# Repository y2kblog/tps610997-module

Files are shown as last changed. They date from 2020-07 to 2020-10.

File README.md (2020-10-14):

# TPS610997 超低消費電力 5V出力昇圧モジュール

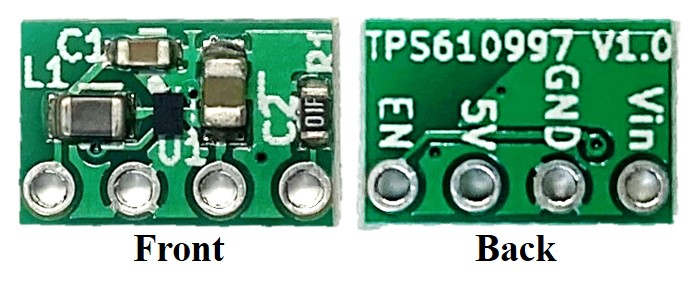
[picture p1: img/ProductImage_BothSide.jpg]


## 概要

超低消費電力の5V出力昇圧型DC-DCコンバータ TPS610997 (Texas Instruments Inc.製) を搭載したモジュールです。  
TPS610997の**静止電流は約1μA程度**と非常に低く、また**0.7Vから動作**するため、コイン電池1個、もしくはアルカリ／ニカド／ニッケル水素乾電池1～2本で駆動するアプリケーションに適しています。  
さらに、TPS610997は**イネーブルピンによりシャットダウンが可能**であり、シャットダウン時は負荷が入力電源から切断されるため消費電流を低減できます。

### 仕様
- 入力電圧：0.7V～5.5V
- 出力電圧：5V (軽負荷時：5.15V)
- 最大出力電流：300mA（3.3V入力時）
  ※最大出力電流は入力電圧と効率に依存します
- 静止電流：1μA (軽負荷時)
- イネーブルピン付き（ENピンをVinピンに接続すると5V昇圧機能が有効化されます）
- 効率
  - 75% (入力電圧3.3V、負荷10μA)
  - 93% (入力電圧3.3V、負荷200mA)
- 基板サイズ：10mm × 6.35mm
- ピン間隔：2.54mm

## 販売  
[スイッチサイエンス委託販売ページ](https://www.switch-science.com/catalog/6505/)  
※大量注文や在庫に関する問い合わせは[こちら](mailto:info.y2kb@gmail.com)までご連絡ください。  

### 回路図  
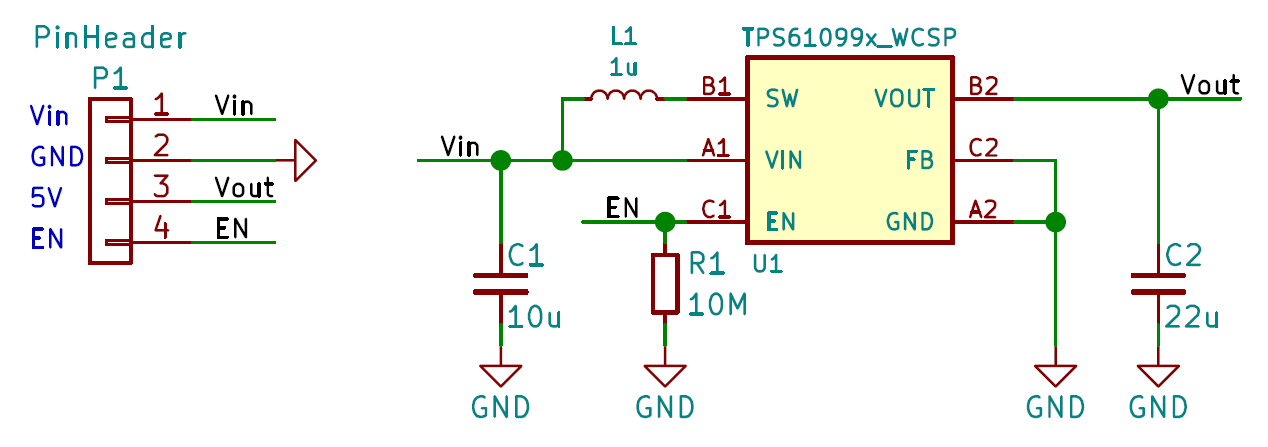
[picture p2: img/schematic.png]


## 性能評価  

### 消費電流 (シャットダウン時 / 負荷100kΩ時 / 負荷1kΩ時)
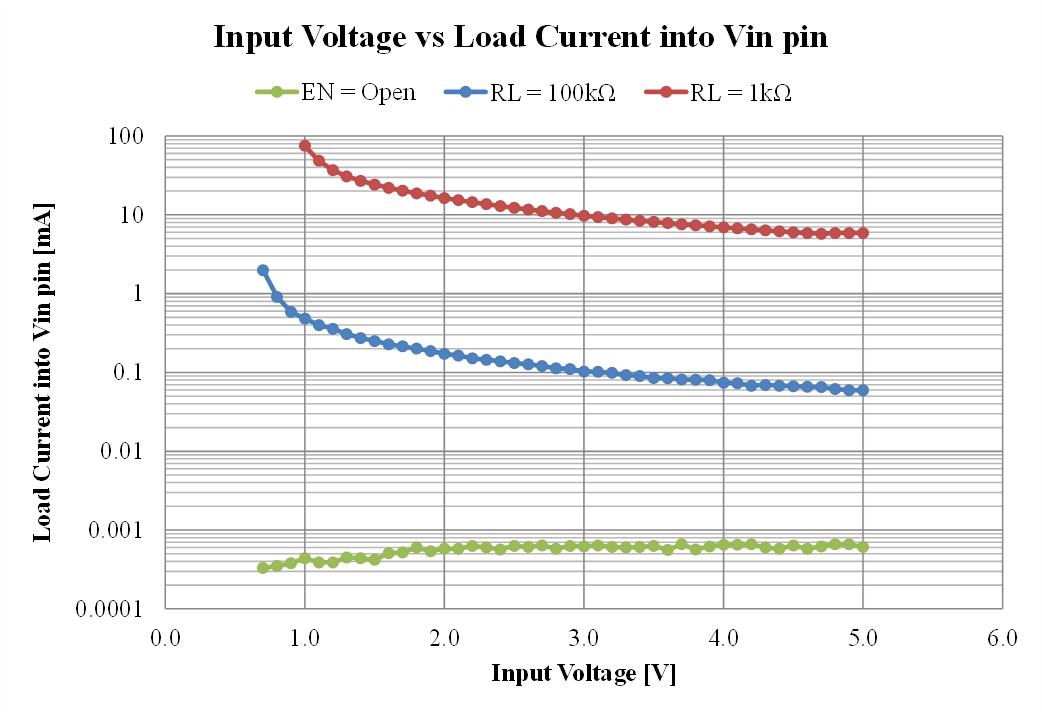
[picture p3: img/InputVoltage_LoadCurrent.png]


## データシート  
[TPS61099xデータシート(日本語)](https://www.tij.co.jp/jp/lit/gpn/tps61099)

## License
MIT License

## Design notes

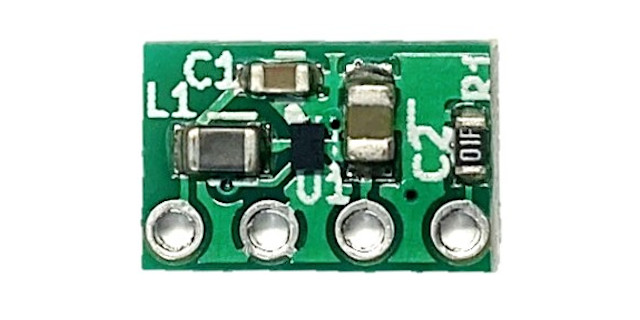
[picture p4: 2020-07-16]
img/ProductImage_sns.jpg

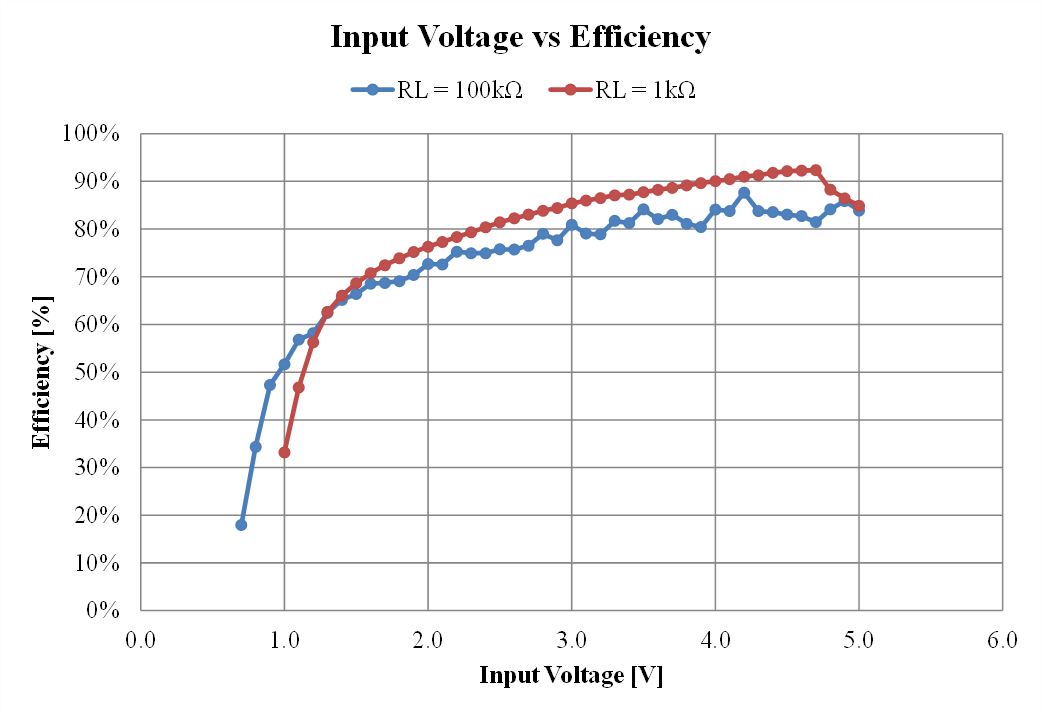
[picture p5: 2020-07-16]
img/InputVoltage_Efficiency.png

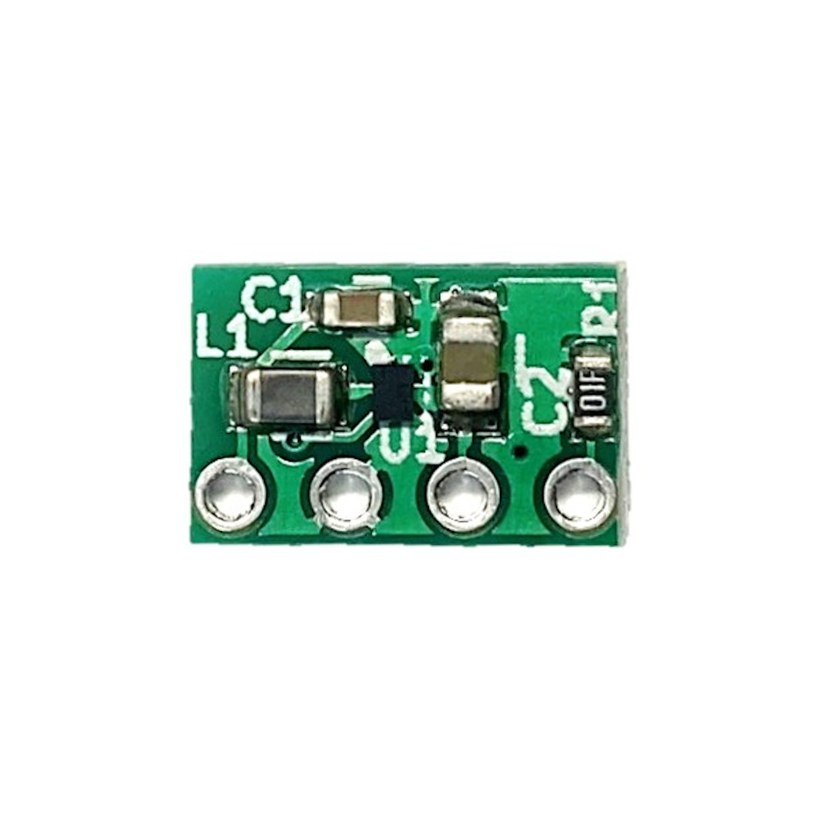
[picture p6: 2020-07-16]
img/ProductImage.jpg

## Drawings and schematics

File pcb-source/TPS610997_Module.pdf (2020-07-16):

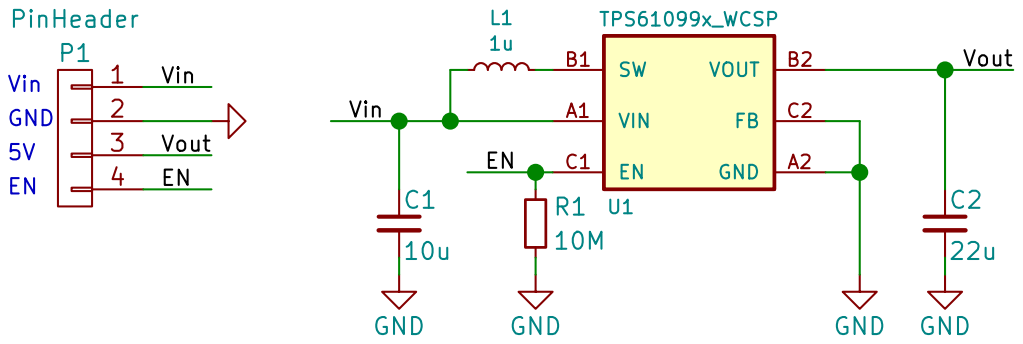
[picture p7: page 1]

Vout Vin Vin GND

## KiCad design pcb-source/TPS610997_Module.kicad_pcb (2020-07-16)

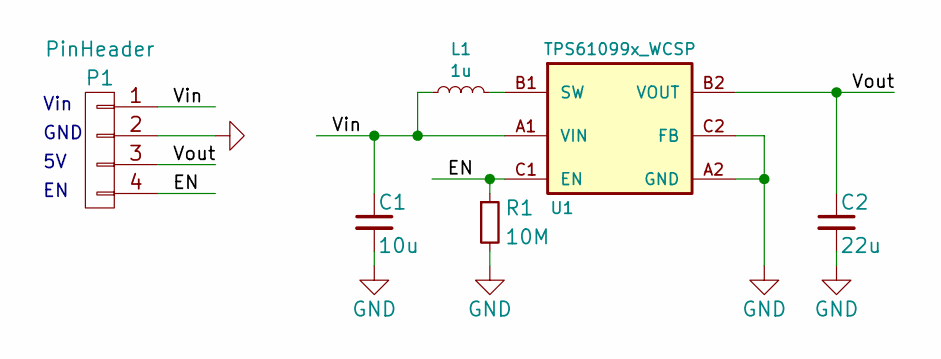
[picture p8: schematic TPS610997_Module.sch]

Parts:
C1: 10u; C_0603
C2: 22u; C_0805
L1: 1u; L_0805
P1: PinHeader; USER_SIL-4_NoSilk
R1: 10M; R_0603
U1: TPS61099x_WCSP; USER_Boost_TPS61099x_WCSP

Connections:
/EN: P1.4, R1.1, U1.C1 (EN)
/Vin: C1.1, L1.1, P1.1, U1.A1 (VIN)
/Vout: C2.1, P1.3, U1.B2 (VOUT)
GND: C1.2, C2.2, P1.2, R1.2, U1.A2 (GND), U1.C2 (FB)
unnamed: L1.2, U1.B1 (SW)

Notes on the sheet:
GND
Vin

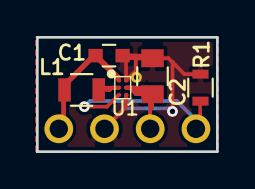
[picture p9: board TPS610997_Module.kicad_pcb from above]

Board: 2 copper layers, 10.0 x 6.3 mm, 6 parts (0 on the bottom side), 5 nets.
